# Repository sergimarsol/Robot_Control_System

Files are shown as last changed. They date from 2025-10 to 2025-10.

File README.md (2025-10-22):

# MSP430FR2355 Robot Control System

This repository contains the complete development of a robotic control system based on the MSP430FR2355 microcontroller. The project encompasses hardware design, embedded software development, real-time control implementation, and autonomous behavior strategies. All stages—from conceptual engineering to full system deployment—were carried out by a single author.

## Project Overview

The system enables robot control through multiple operational modes, leveraging a modular driver-based firmware architecture. It integrates input devices, actuators, and display components to provide both manual and autonomous control functionalities. The hardware was designed, assembled, debugged, and calibrated to ensure correct interaction among all peripherals.

### Control Modes
- **Joystick Mode**: Manual navigation using an analog joystick.
- **Light-Following Mode**: Robot movement directed toward the strongest detected light using LDR readings.
- **Line-Following Mode**: Ground sensor-based autonomous navigation via line detection.
- **Main Menu Interface**: LCD-driven user interface navigated using the joystick.

## Hardware Architecture

| Component | Description |
|---|---|
| MSP430FR2355 MCU | Core controller handling I2C, ADC, timers, GPIOs |
| 32.7KHz Crystal | Clock stabilization |
| SBW Connector | Programming and debugging interface |
| LCD 16x2 (I2C) | Displays system information and menu |
| Joystick | Directional input for manual control and navigation |
| LDR Sensors (ADC) | Detect light intensity for autonomous movement |
| Motor Driver (I2C) | Controls wheel motors for robot movement |
| RGB LEDs (I2C) | Status indication |
| ESP-01 Module (UART) | Planned Wi-Fi communication support |

## Software Architecture

The firmware was implemented with a modular structure to maximize maintainability and reusability.

| Module | Purpose |
|---|---|
| `main.c` | System initialization and main control loop |
| `timer.h` | Timer configuration, delays, millisecond counter ISR |
| `i2c.h` | I2C communication management and ISR |
| `lcd.h` | LCD initialization and text display functions |
| `leds.h` | RGB LED color control |
| `motors.h` | Motor control for direction and velocity |
| `joystick.h` | Joystick reading and movement triggering |
| `adc.h` | Light sensor acquisition and averaging |
| `sensors.h` | Line detection and autonomous path adjustment |

## Proposed Repository Structure

```
MSP430-Robot-Control-System
├── hardware/
│   ├── SergiMarsol_Gerber/                  # Gerber manufacturing outputs
│   ├── SergiMarsol_projecte_MISE.kicad_pro  # KiCad project file
│   ├── SergiMarsol_projecte_MISE.kicad_sch  # Schematic design
│   ├── SergiMarsol_projecte_MISE.kicad_pcb  # PCB layout
│   ├── SergiMarsol_projecte_MISE-backups/   # KiCad auto-backups
│   ├── SergiMarsol_projecte_MISE.kicad_prl  # KiCad project local settings
│   ├── fp-info-cache                        # Footprint cache
│   └── fp-lib-table                         # Footprint library table
├── firmware/
│   ├── ADC.c
│   ├── ADC.h
│   ├── i2c.c
│   ├── i2c.h
│   ├── joystick.c
│   ├── joystick.h
│   ├── lcd.c
│   ├── lcd.h
│   ├── leds.c
│   ├── leds.h
│   ├── motors.c
│   ├── motors.h
│   ├── sensors.c
│   ├── sensors.h
│   ├── timer.c
│   ├── timer.h
│   ├── main.c
│   ├── lnk_msp430fr2355.cmd                 # Linker command file
│   ├── Debug/                               # Compilation artifacts
│   └── targetConfigs/                       # MCU target configuration files
├── documents/
│   └── presentation.pdf                       # Final presentation of the project (in Catalan)
└── README.md
```

## Development Highlights

| Phase | Achievement |
|---|---|
| Concept Engineering | Block diagrams, requirements, planning |
| Hardware Implementation | Complete schematic design, assembly, correction of ADC pin assignments |
| Software Implementation | Driver-based structure enabling scalability |
| Debugging | Systematic validation using modular subsystem tests |
| Optional Expansion | UART-based Wi-Fi communication ready for future phases |

## Conclusion

The project demonstrates an end-to-end realization of an embedded robotic control system, showcasing microcontroller-based hardware integration, real-time firmware development, and autonomous control strategies. It serves as an excellent reference for modular embedded system design using the MSP430 ecosystem.

---

For future developments, planned features include remote control via Wi-Fi, telemetry reporting, and enhanced control algorithms such as PID for smoother autonomous navigation.

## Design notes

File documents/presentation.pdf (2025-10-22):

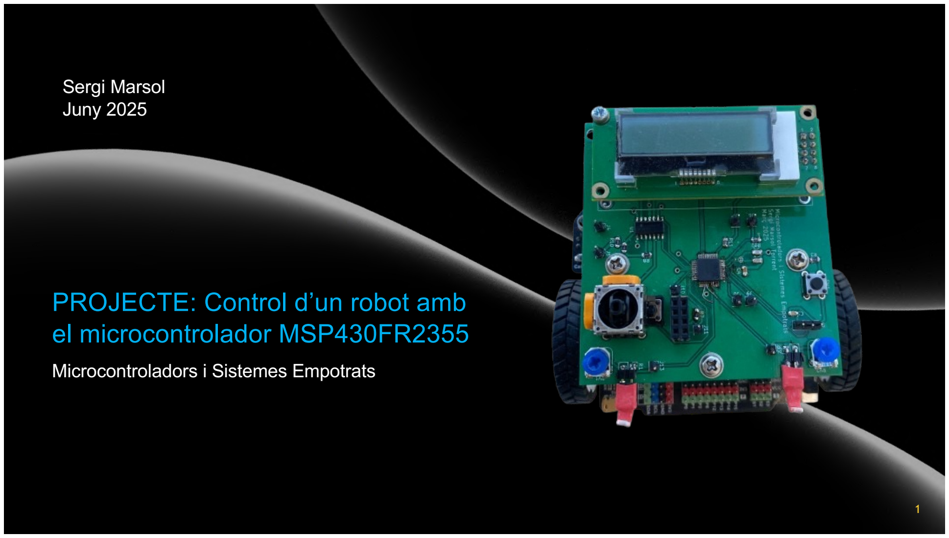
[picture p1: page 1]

## PROJECTE: Control d’un robot amb el microcontrolador MSP430FR2355

Microcontroladors i Sistemes Empotrats

Sergi Marsol
Juny 2025

1

## I N T R O D U C C I Ó

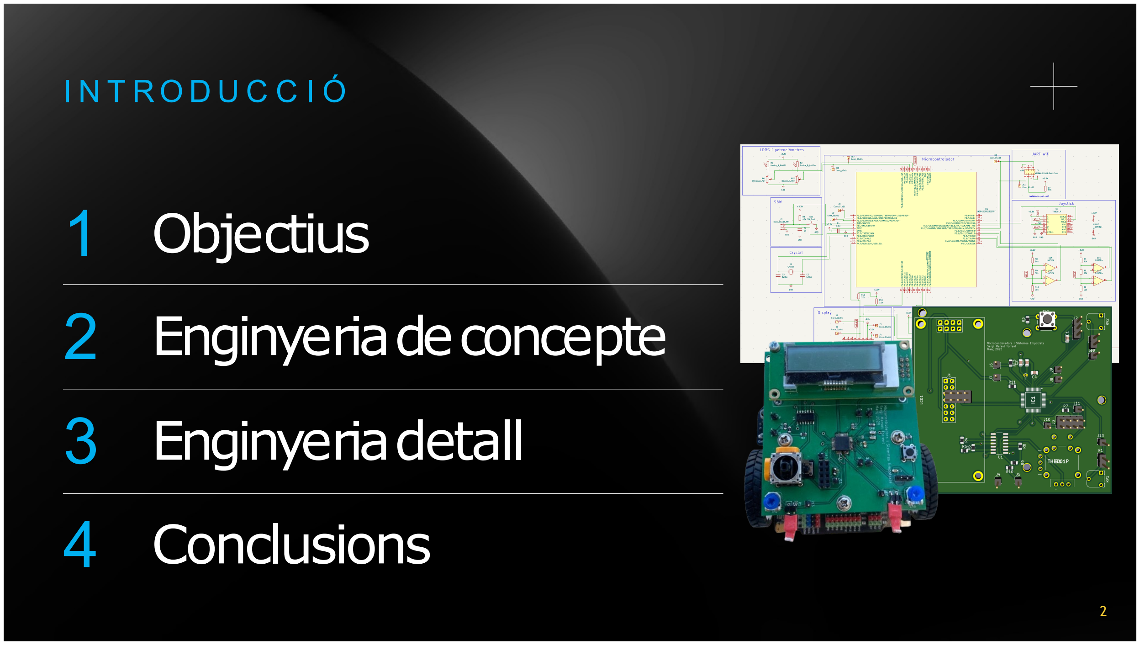
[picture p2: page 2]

1
2
3
4

# Objectius Enginyeriadeconcepte

# Enginyeriadetall

# Conclusions

2

# OBJECTIUS

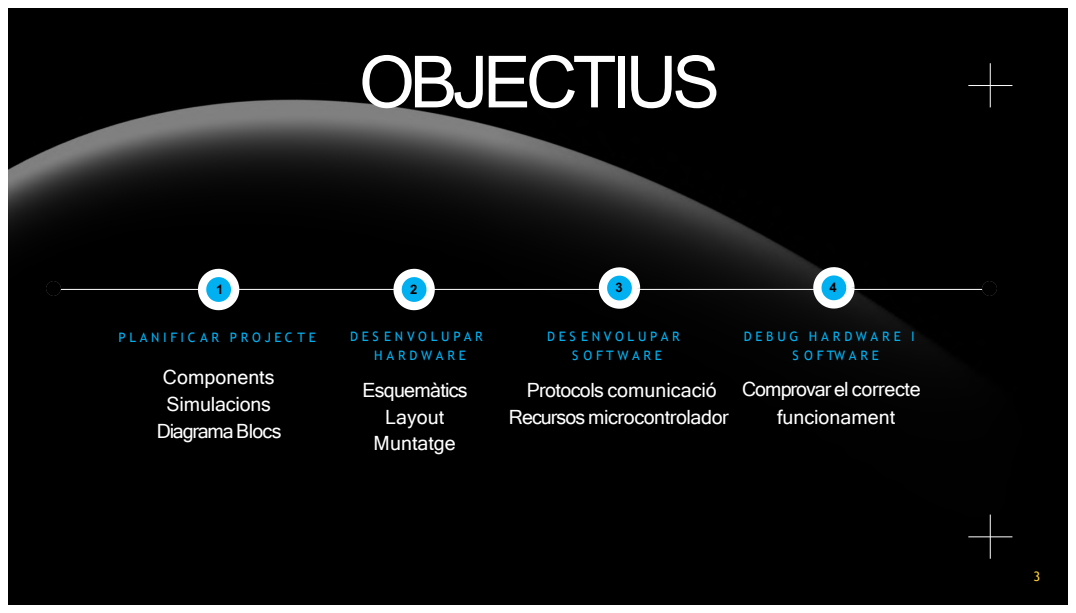
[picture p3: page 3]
Esquemàtics Layout Muntatge; Protocols comunicació Recursos microcontrolador; Components Simulacions DiagramaBlocs

Comprovar el correcte
funcionament

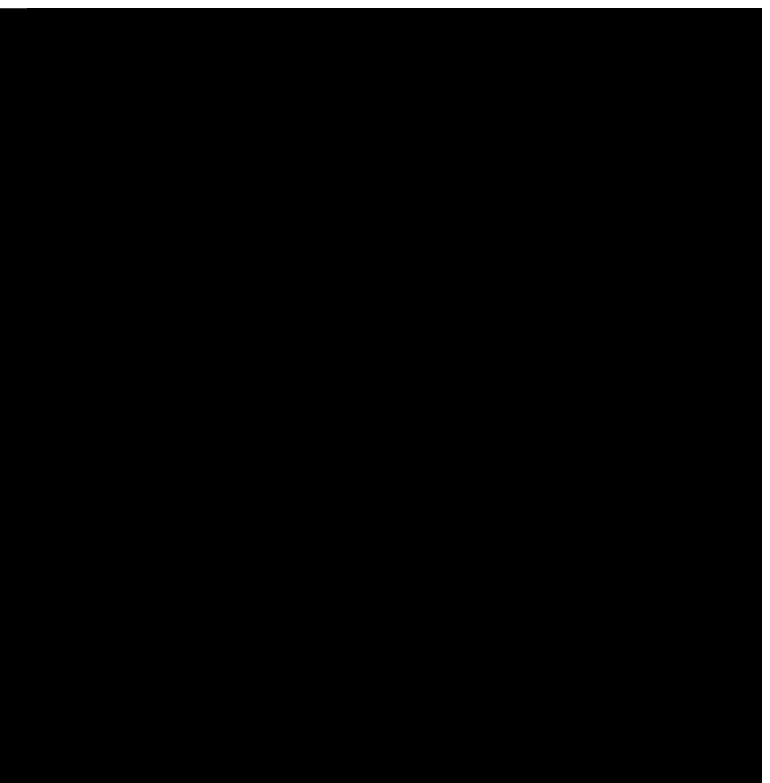
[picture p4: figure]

# ENGINYERIADECONCEPTE

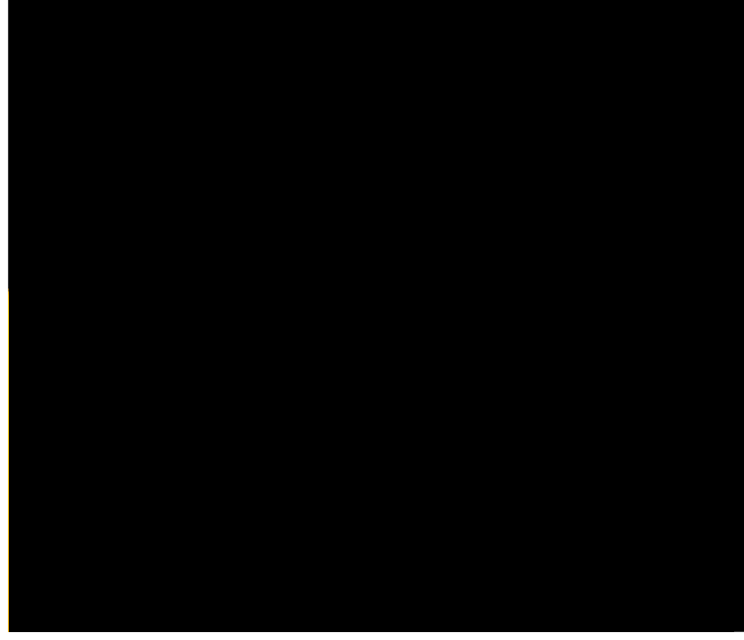
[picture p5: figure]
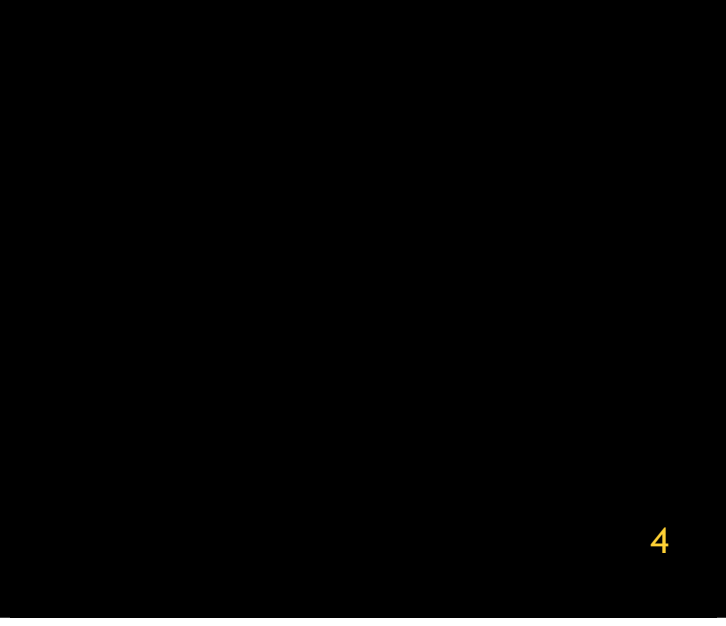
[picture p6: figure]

# REQUERIMENTS

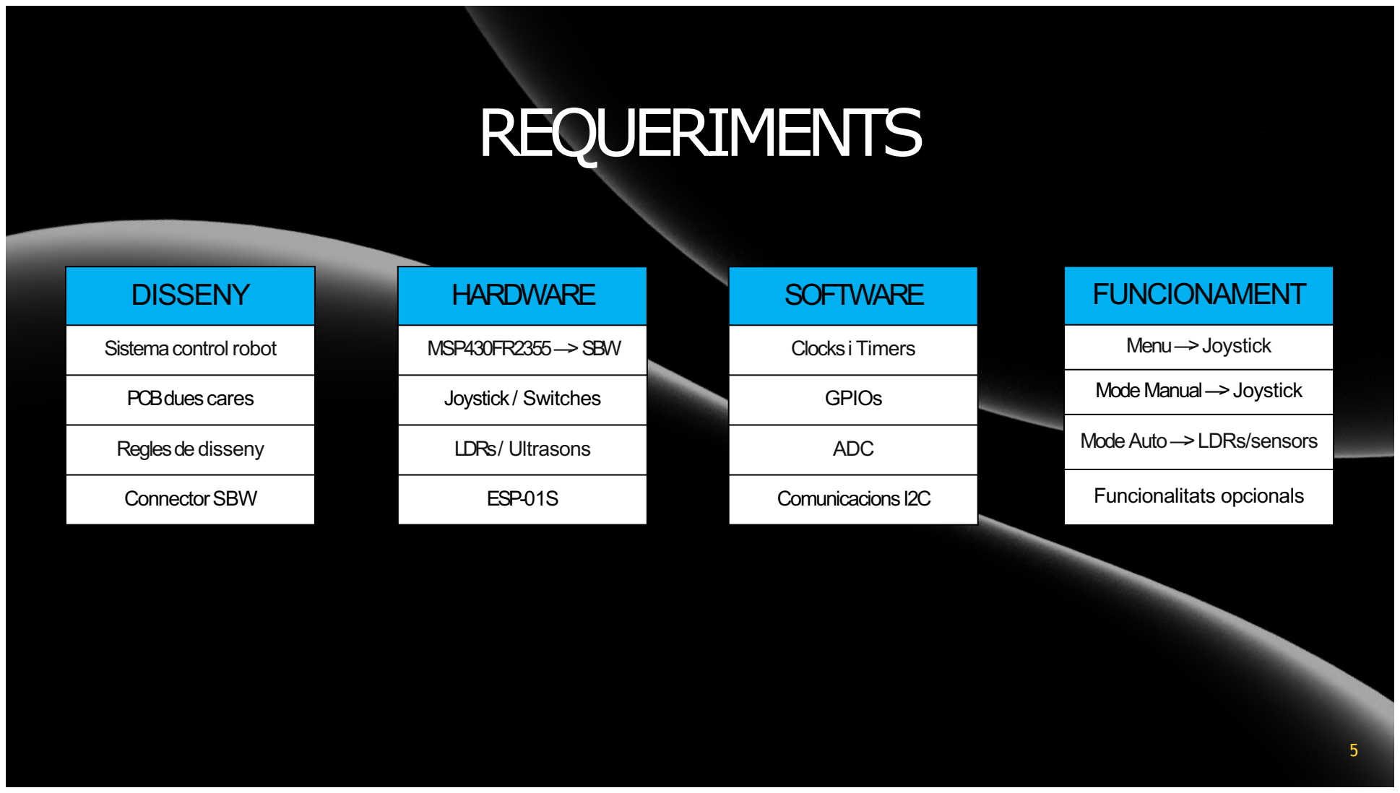
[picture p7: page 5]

### DISSENY

Sistemacontrolrobot

PCBduescares

Reglesde disseny

ConnectorSBW

### HARDWARE

MSP430FR2355—>SBW

Joystick / Switches

LDRs/ Ultrasons

ESP-01S

### SOFTWARE

Clocksi Timers

GPIOs

ADC

ComunicacionsI2C

### FUNCIONAMENT

Menu—>Joystick

Mode Manual—>Joystick

ModeAuto—>LDRs/sensors

Funcionalitats opcionals

5

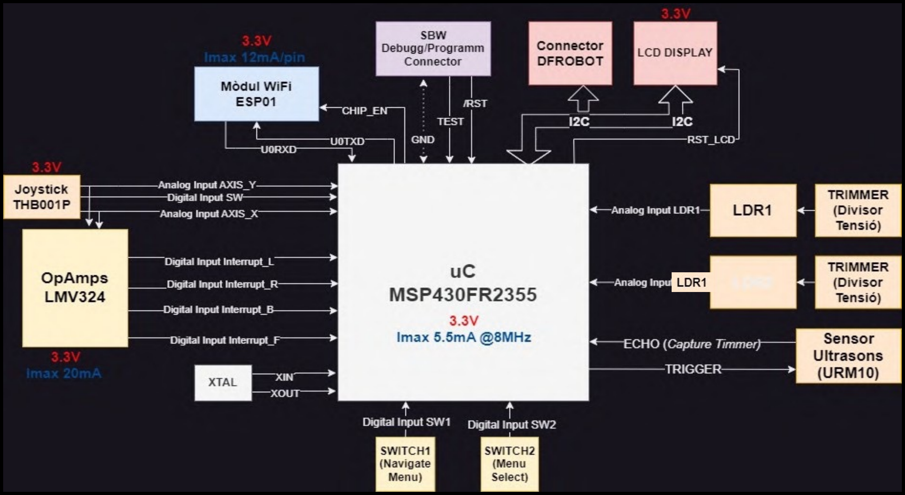
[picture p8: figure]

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
# ENGINYERIADE DETALL

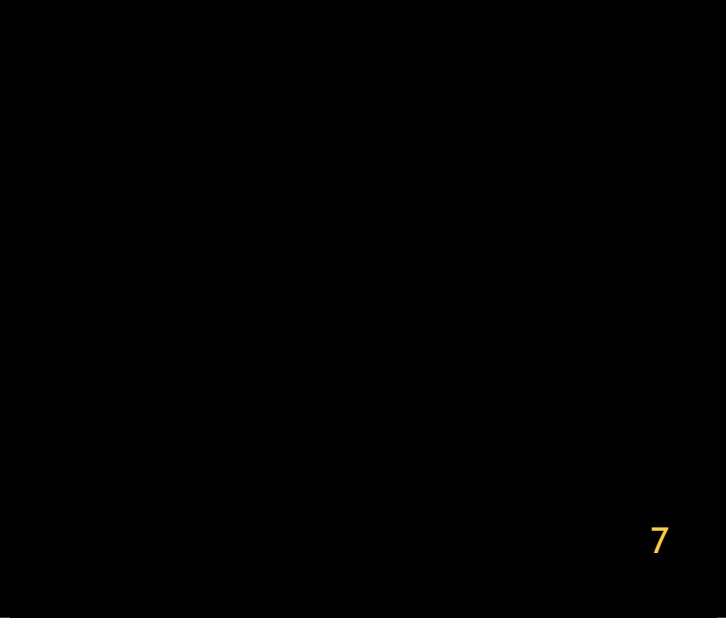
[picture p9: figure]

# HARDWARE

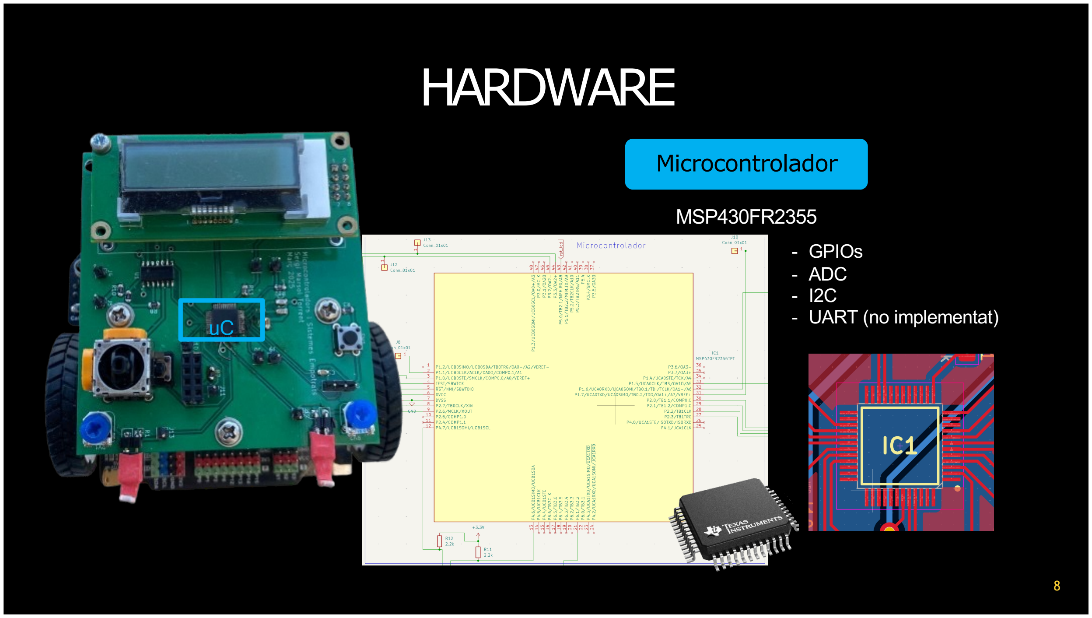
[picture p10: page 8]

uC

## Microcontrolador

MSP430FR2355
- GPIOs
- ADC
- I2C
- UART (no implementat)

8

# HARDWARE

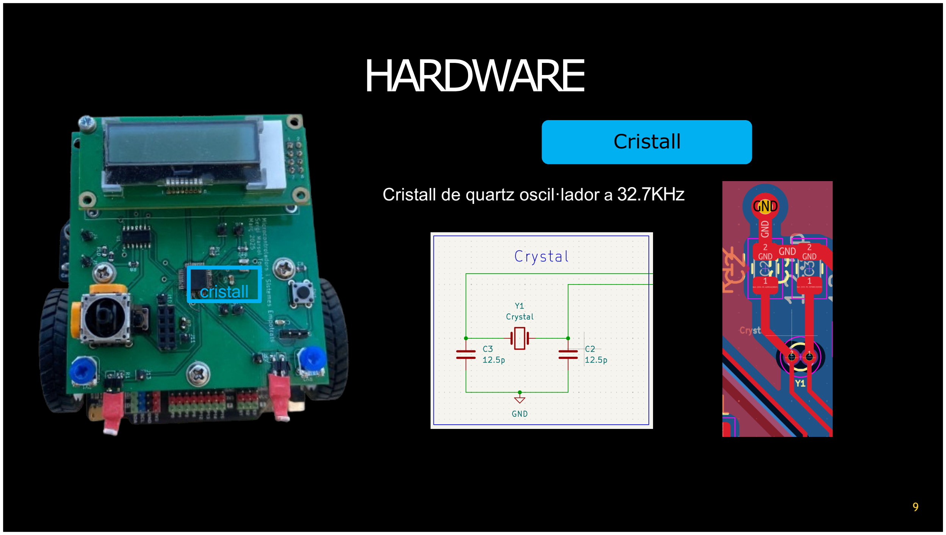
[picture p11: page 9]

## Cristall

Cristall de quartz oscil·lador a 32.7KHz

cristall

9

# HARDWARE

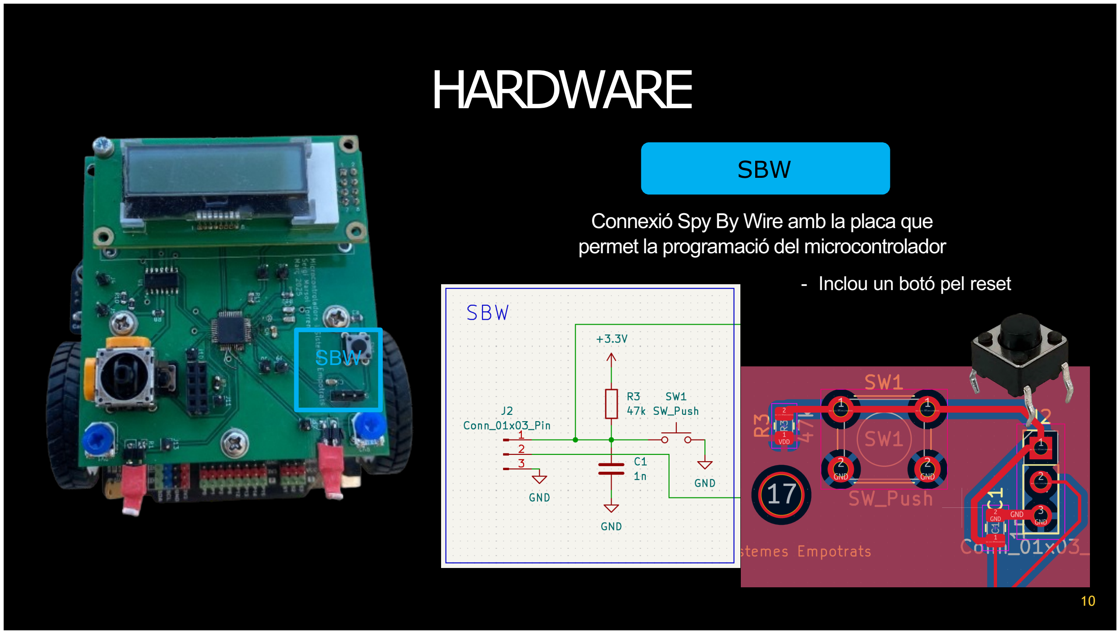
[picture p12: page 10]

## SBW

Connexió Spy By Wire amb la placa que permet la programació del microcontrolador

SBW

- Inclou un botó pel reset

10

# HARDWARE

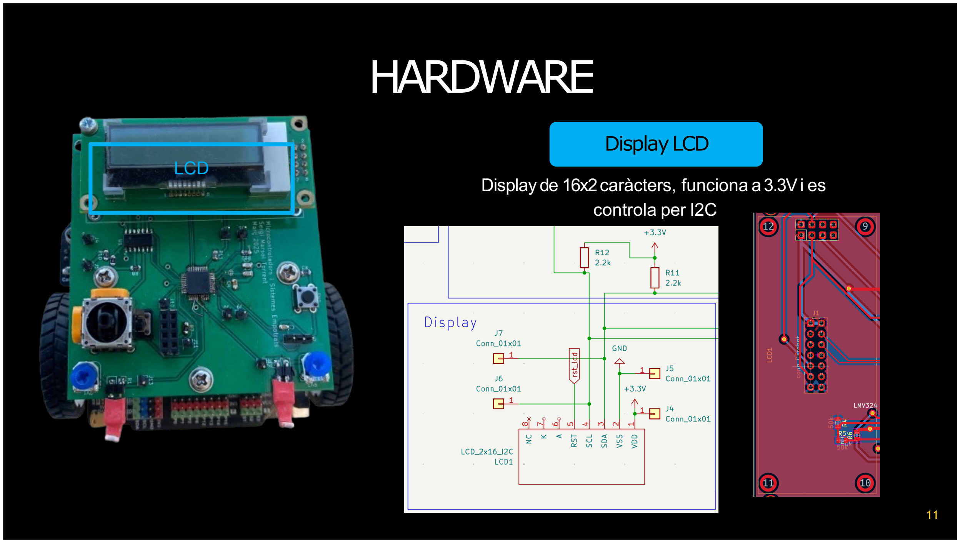
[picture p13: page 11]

## DisplayLCD

Display de 16x2caràcters, funciona a3.3Vi es controla per I2C

LCD

11

# HARDWARE

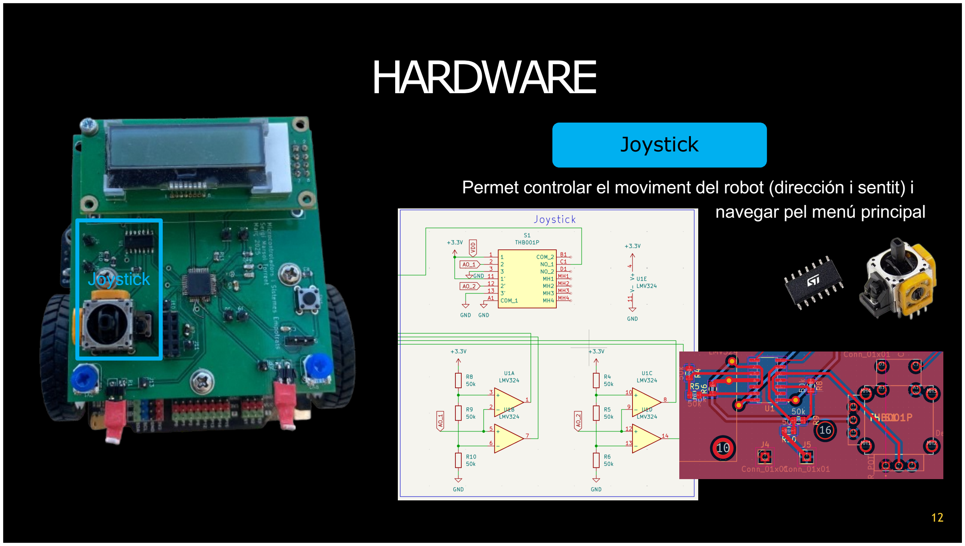
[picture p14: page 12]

## Joystick

Joystick

Permet controlar el moviment del robot (dirección i sentit) i navegar pel menú principal

12

# HARDWARE

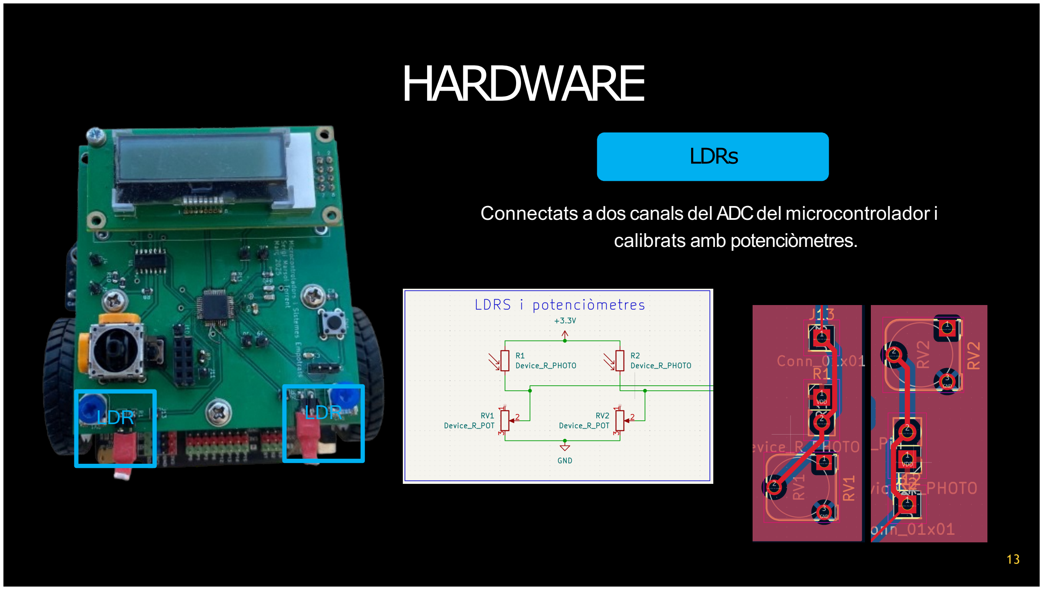
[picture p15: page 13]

## LDRs

Connectats a dos canals del ADC del microcontrolador i calibrats amb potenciòmetres.

LDR | LDR

13

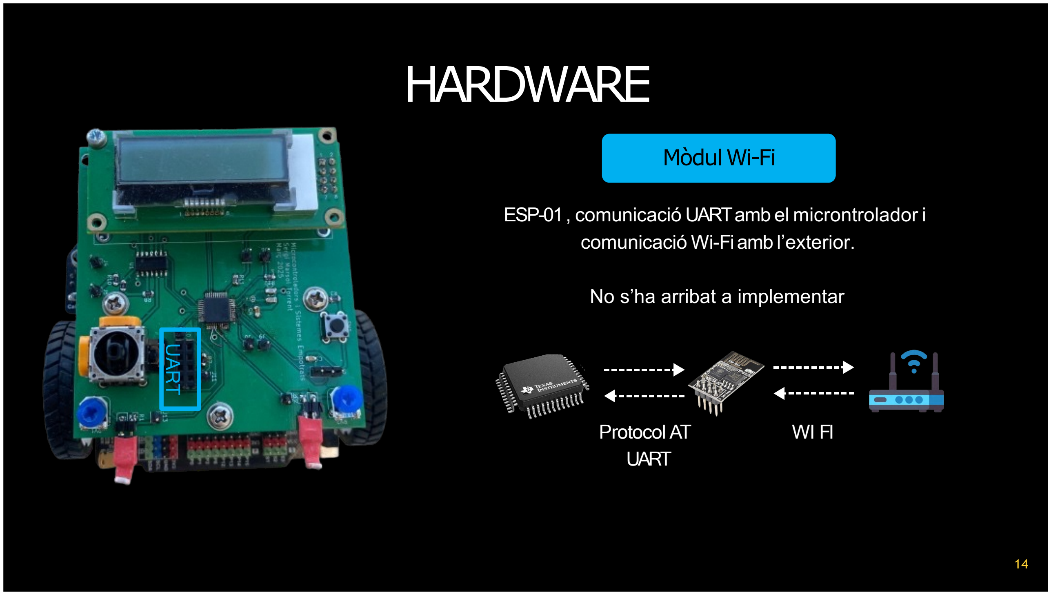
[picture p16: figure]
HARDWARE; MòdulWi-Fi; comunicació Wi-Fi amb l’exterior.; No s’ha arribat a implementar; Protocol AT UART; UART

ESP-01, comunicació UARTamb el microntrolador i

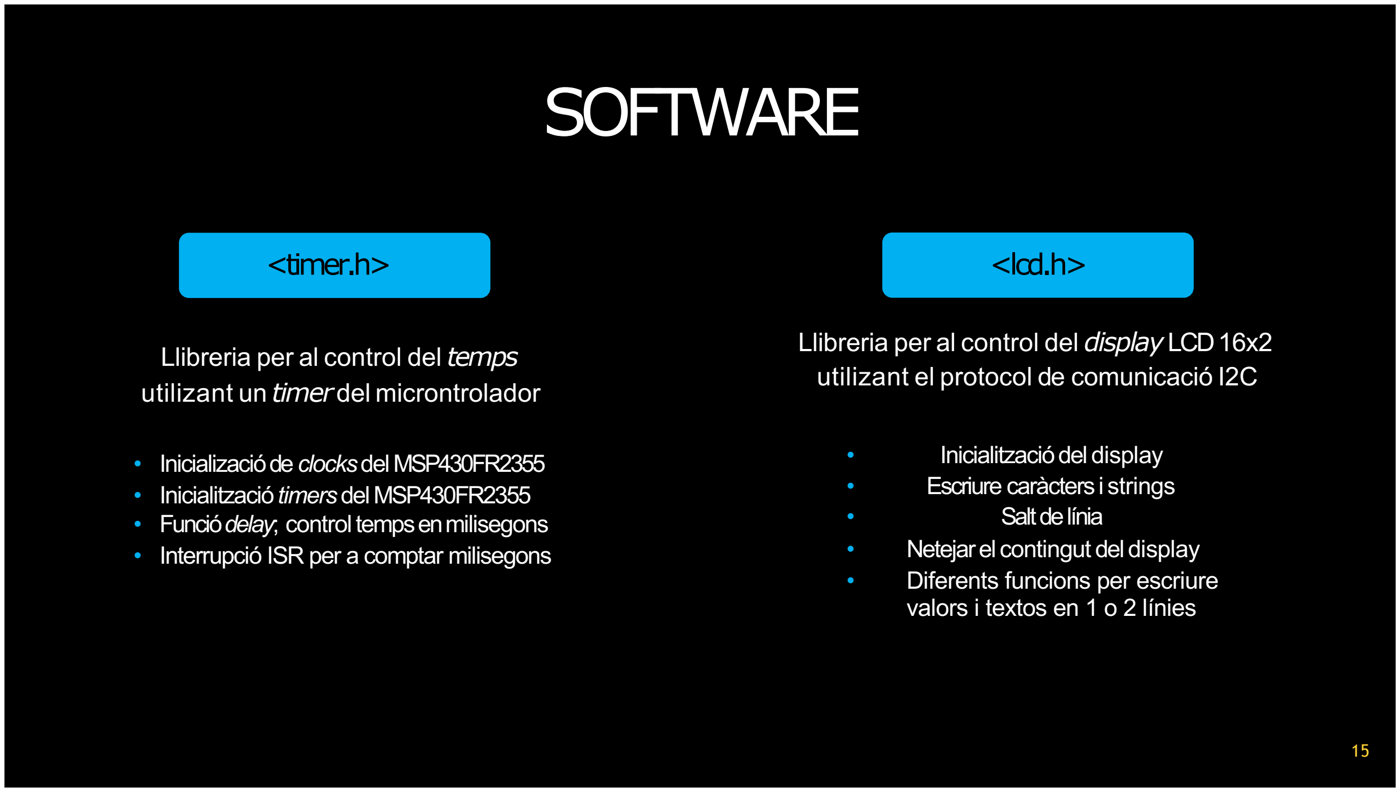
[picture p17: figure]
SOFTWARE; <timer.h>; Llibreria per al control del temps utilizant un timerdel microntrolador; • Inicializacióde clocksdel MSP430FR2355 • Inicialitzaciótimers del MSP430FR2355 • Funciódelay; control tempsenmilisegons; <lcd.h>; • Inicialitzaciódel display • Escriure caràcters i strings • Salt de línia • Netejarel contingut deldisplay • Diferents funcions per escriure valors i textos en 1 o 2 línies

- Interrupció ISR per a comptar milisegons

Llibreria per al control del displayLCD16x2 utilizant el protocol de comunicació I2C

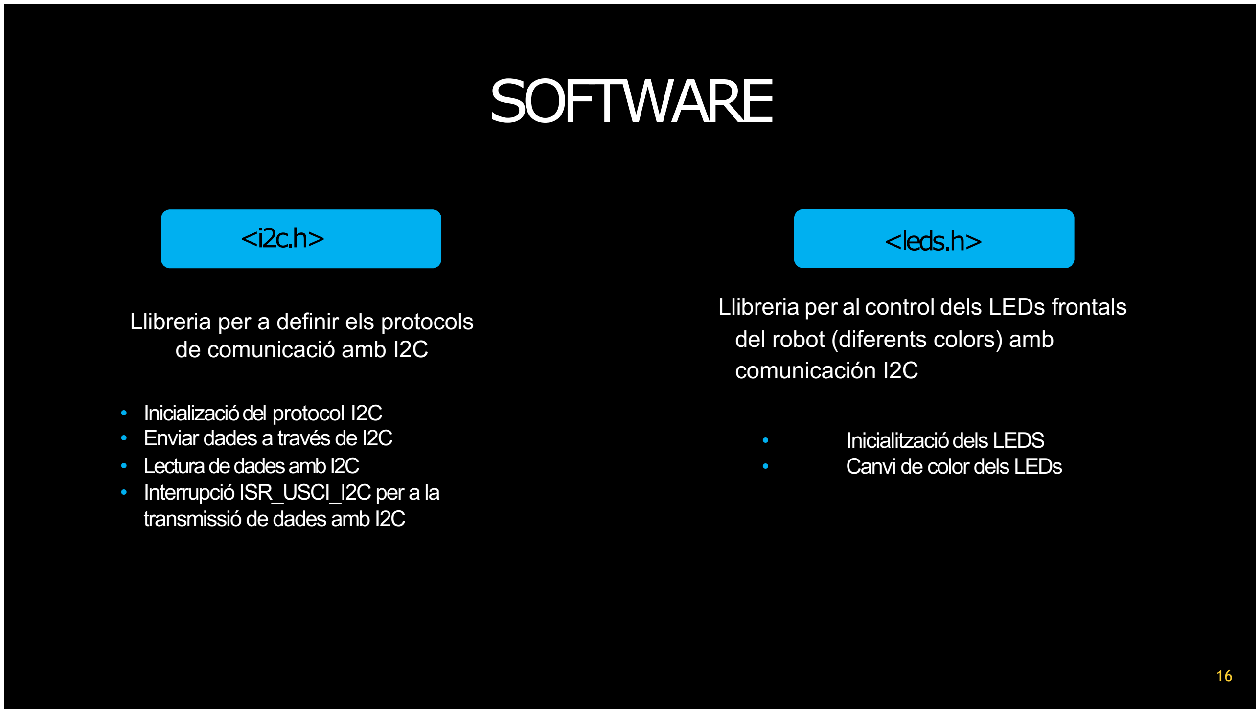
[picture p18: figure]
SOFTWARE; Llibreria per a definir els protocols de comunicació amb I2C; • Inicializaciódel protocol I2C • Enviar dades a través de I2C • Lectura de dades ambI2C • Interrupció ISR_USCI_I2C per a la transmissió de dades amb I2C; <leds.h>; del robot (diferents colors) amb comunicación I2C; • Inicialitzaciódels LEDS • Canvi de color dels LEDs

Llibreria per al control dels LEDs frontals

# SOFTWARE

## <motors.h>

Llibreria per a definir el moviment dels motors de les rodes amb comunicació I2C

- Inicializaciódels motors
- Moviment dels motors donades direccions i velocitat
- Movimentsdel robot en totes direccions (endavant, enrere, dreta, esquerra, aturat)

17

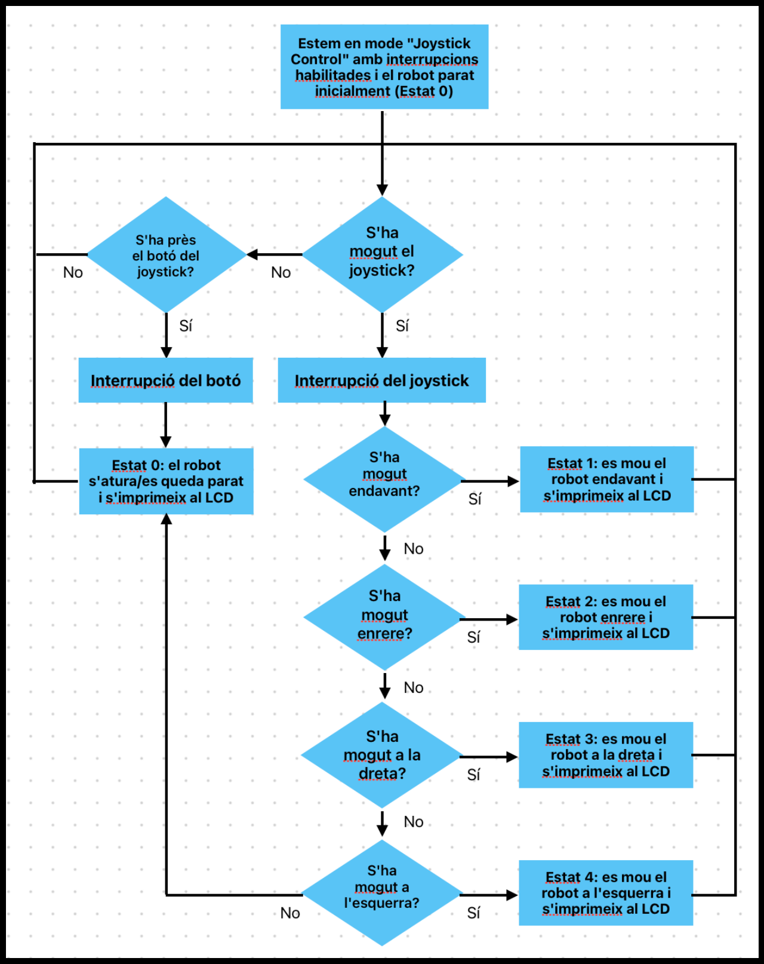
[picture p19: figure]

# SOFTWARE

## <joystick.h>

Llibreria per a la lectura del joystick i el moviment del robot usant-lo

- Inicializaciódel joystick
- Iniciaitzaciódel botódel joystick
- Funcióperdetectarladirecciódel joystick i enviarlacomandaperI2Calmotor
- ISRperladetecciódelssenyalsdel joystick
- ISR per al botó del joystick

F I G U R A 2: DIAGRAMA DE FLUX DEL CONTROL PER JOYSTICK

18

Llibreria per a la lectura dels LDRS i el moviment del robot en la direcció de la llum
- InicializaciódelADC
- Inicialitzar una mesura per el LDR indicat
- Controlar el movement del robot per seguir la llum
- ISR per prendre la mitja de 16 mesures

# SOFTWARE

## <ADC.h>

F I G U R A 3: DIAGRAMA DE FLUX DEL CONTROL PER LLUM (LDRs)

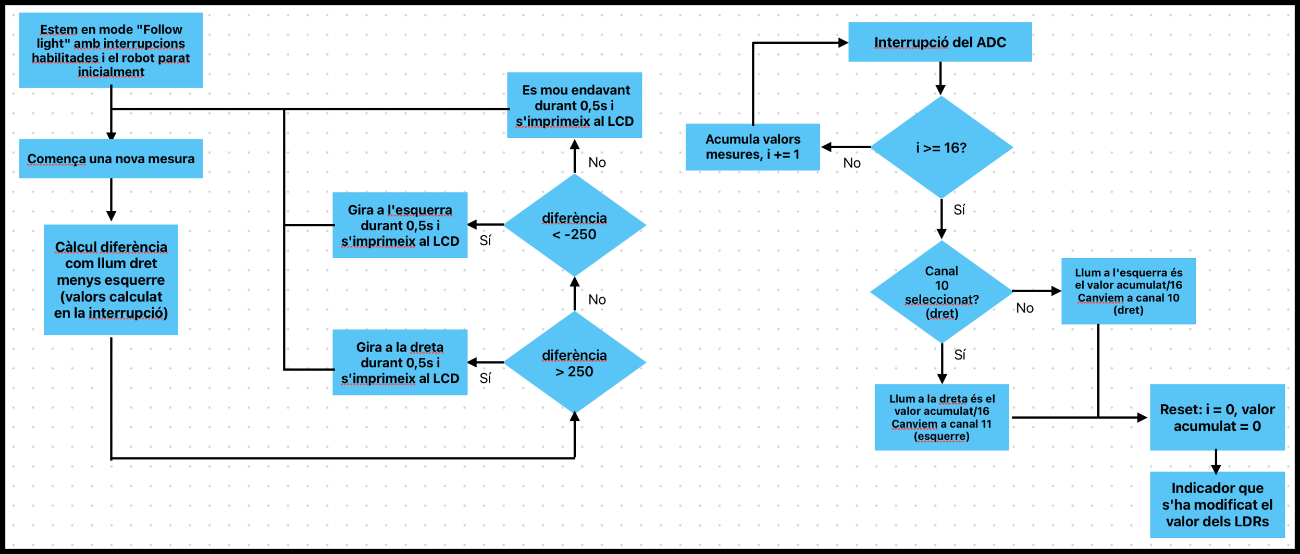
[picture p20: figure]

19

Llibreria per a la lectura dels sensors de la base del robot i el control del seu movement per a seguir línies

- Lectura dels sensors per I2C
- Moviment del robot seguint les línies del terra que es detecten amb els sensors

# SOFTWARE

## <sensors.h>

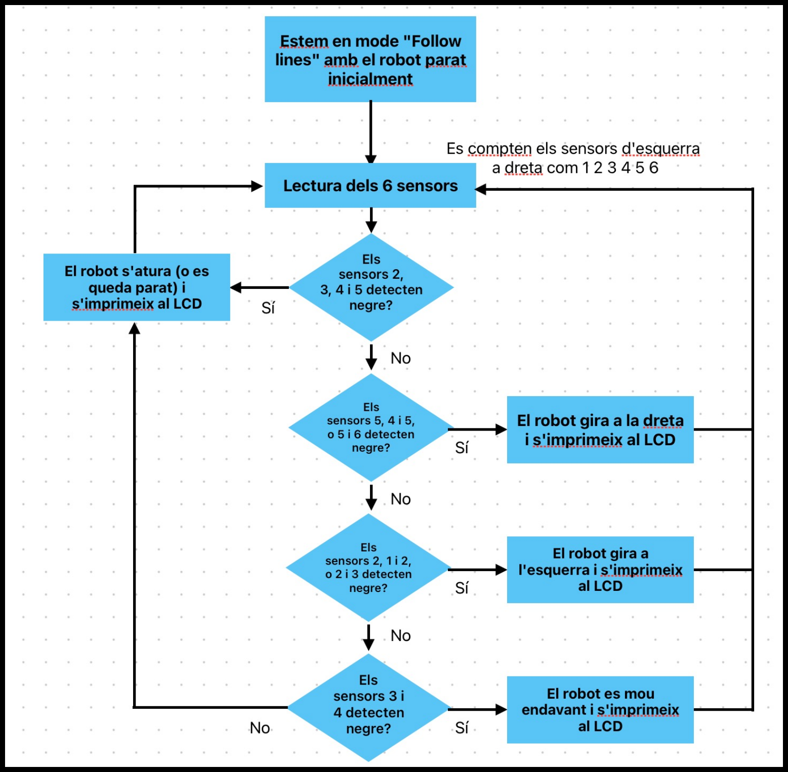
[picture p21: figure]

F I G U R A 4: DIAGRAMA DE FLUX DEL CONTROLPER SEGUIMENT DE LÍNIES | 20

# SOFTWARE <main.c>

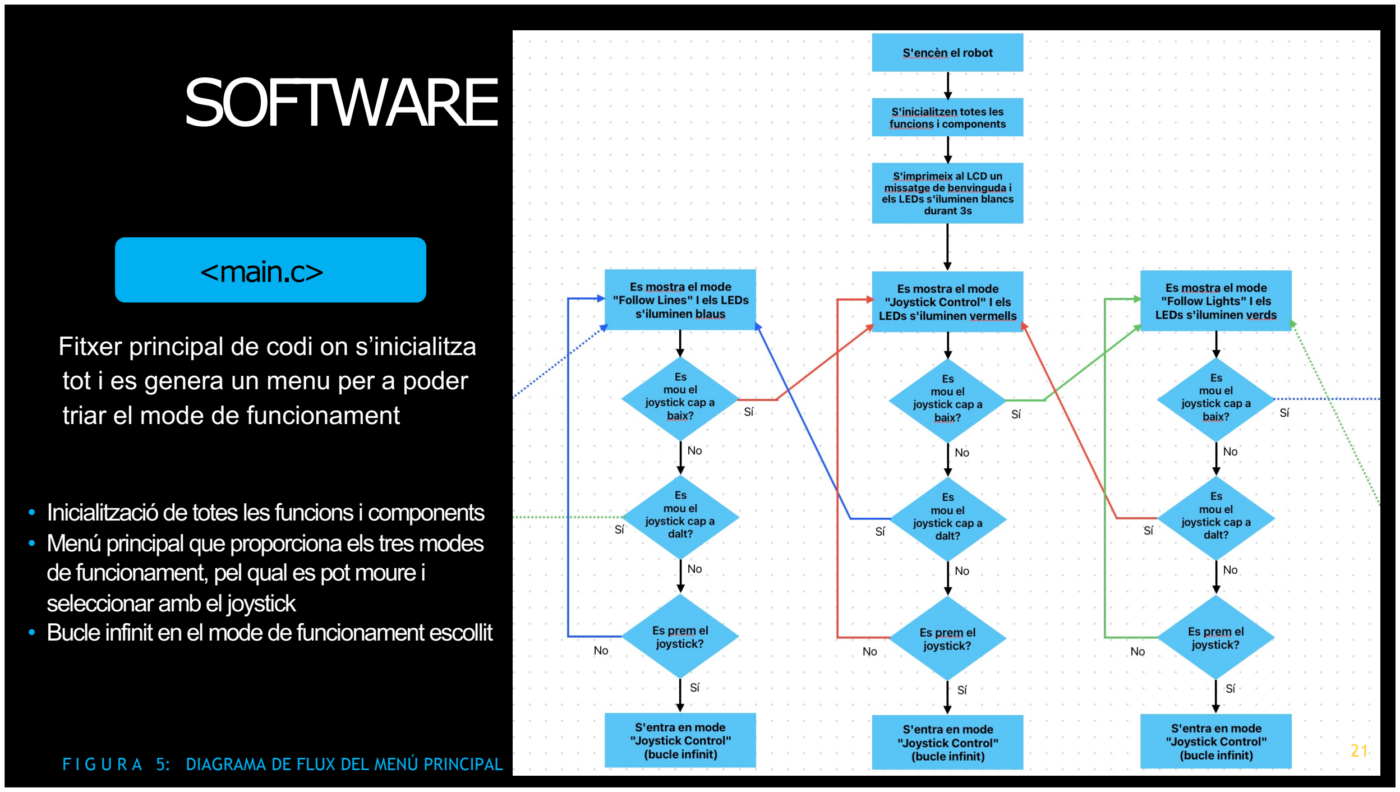
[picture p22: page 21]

Fitxer principal de codi on s’inicialitza tot

i es genera un menu per a poder triar el mode de funcionament

- Inicialització de totes les funcions

i components
- Menú principal que proporciona els tres modes de funcionament, pel qual es pot moure

i
seleccionar amb el joystick
- Bucle infinit en el mode de funcionament escollit

F

I

G

U

R

A

5

: DIAGRAMA DE FLUX DEL MENÚ PRINCIPAL | 21

### S’ha dut a terme una bona planificació del projecte amb components

adequats i un diagrama de blocs complets.

La implementación a nivel hardware s’ha aconseguit de forma satisfactòria,

### però ha calgut canviar el microcontrolador i dues pistes perquè s’havien

conectat a pins senseADC.

Unbon disseny del hardware facilita el debug i la programació del sistema.

### El software s’ha implementat exitosament de manera que ha permés proporcionar totes les funcionalitats obligatòries i algunes de les

opcionals (seguiment de línies).

### En general s’ha aconseguit un projecte complet i functional tot i els

imprevistos que han sorgit i el fet d’haver realitzat el projecte sol.

# CONCLUSIONS

22

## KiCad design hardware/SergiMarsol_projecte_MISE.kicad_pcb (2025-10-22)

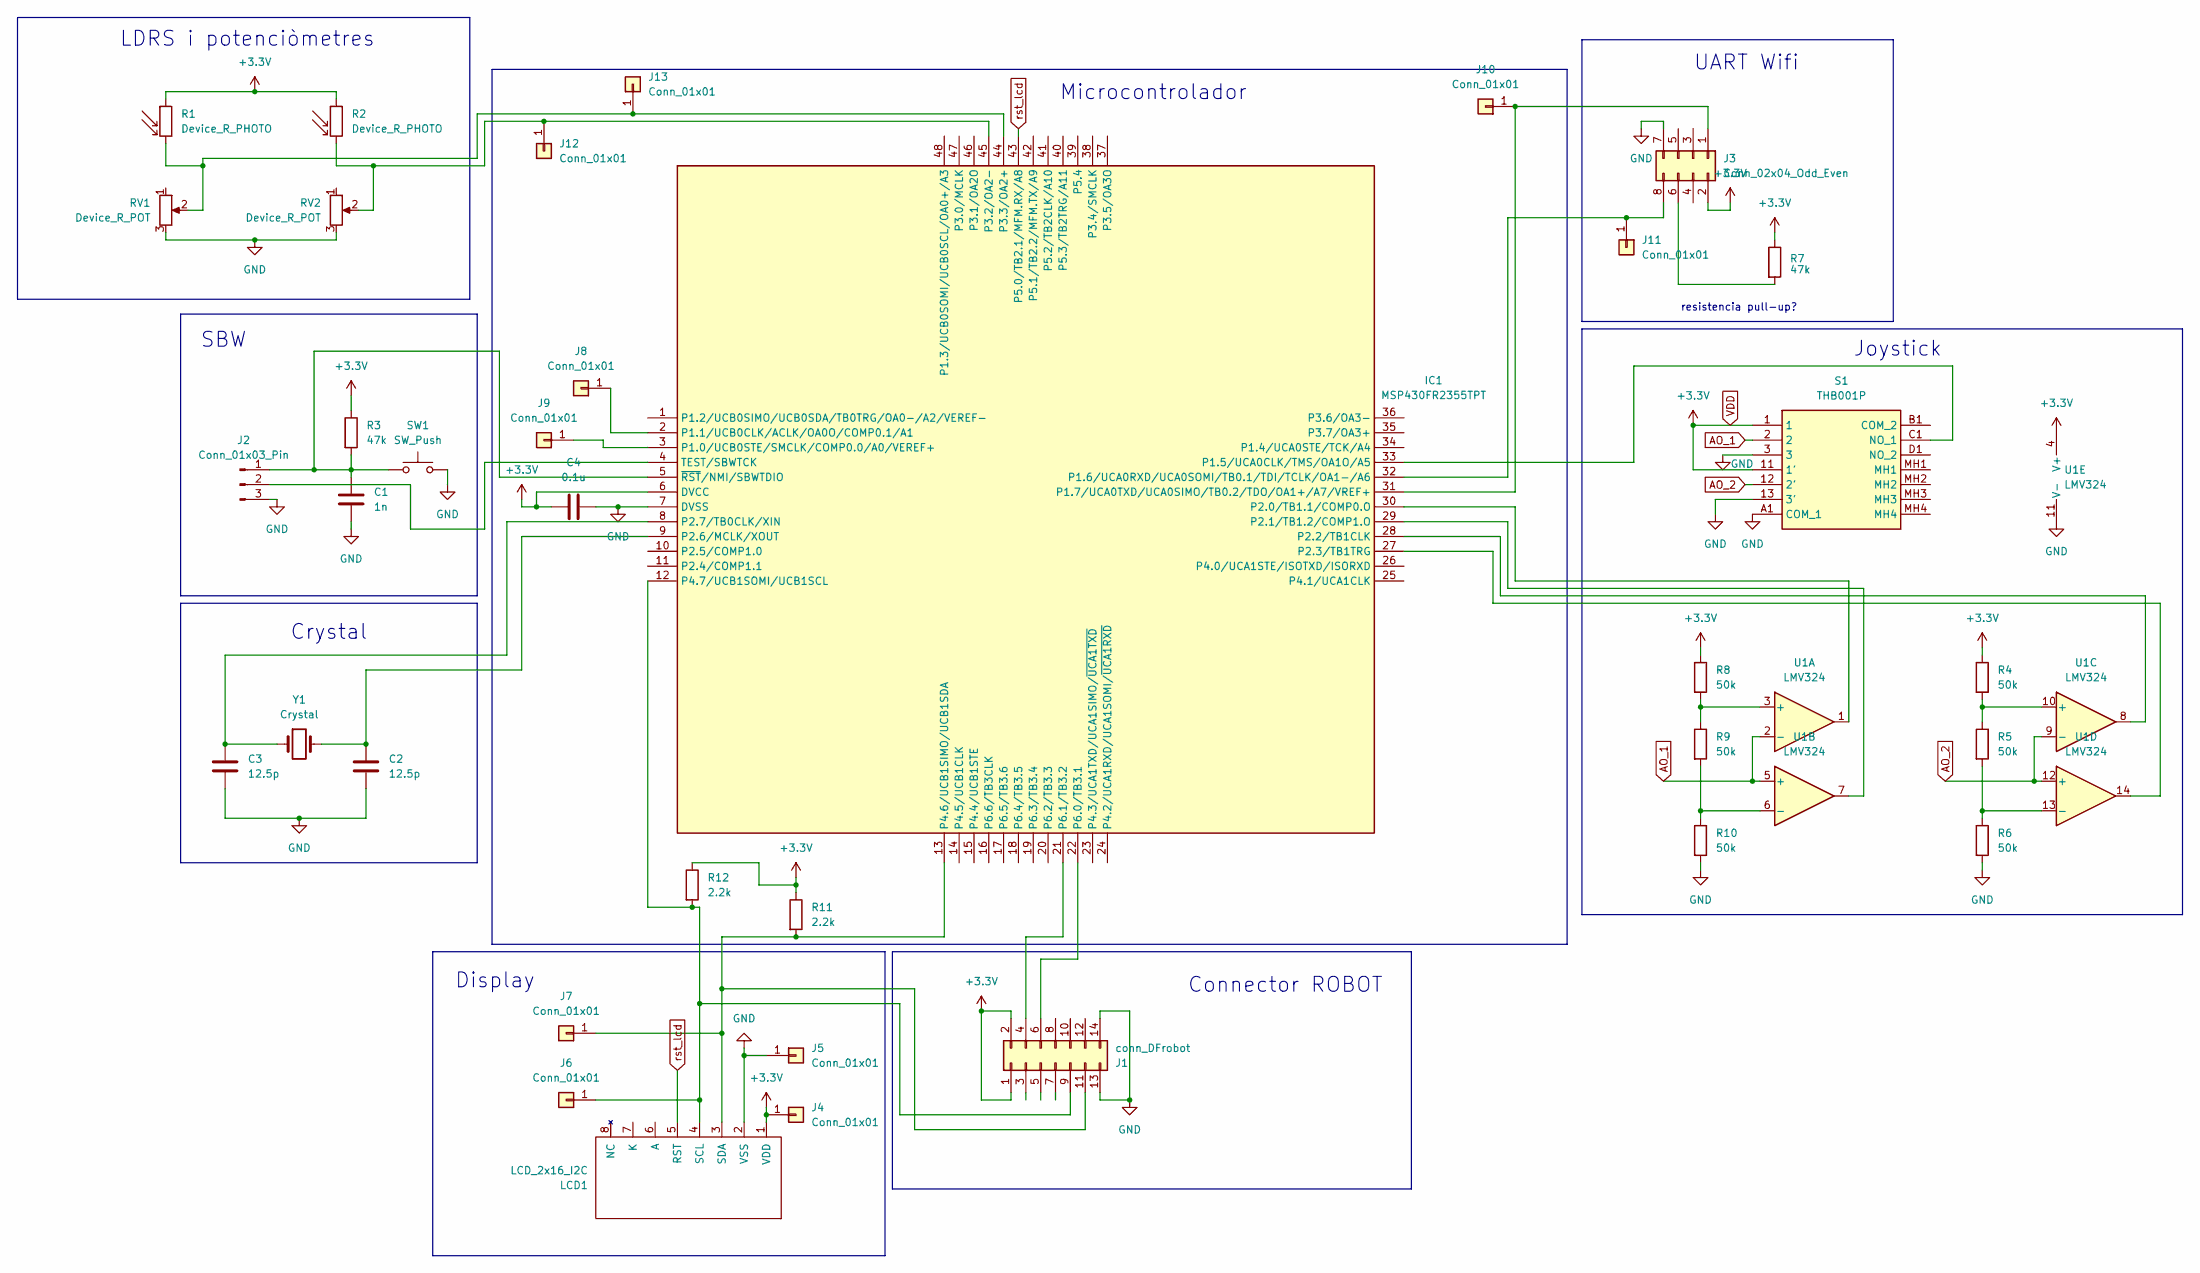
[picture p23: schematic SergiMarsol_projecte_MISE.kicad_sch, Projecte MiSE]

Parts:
C1: 1n; C_0805_2012Metric
C2, C3: 12.5p; C_0805_2012Metric
C4: 0.1u; C_0805_2012Metric
IC1: MSP430FR2355TPT; QFP50P900X900X160-48N; Manufacturer_Part_Number MSP430FR2355TPT; Mouser Part Number 595-MSP430FR2355TPT
J1: conn_DFrobot
J2: Conn_01x03_Pin; PinHeader_1x03_P2.54mm_Vertical
J3: Conn_02x04_Odd_Even; PinHeader_2x04_P2.54mm_Vertical
J4, J5, J6, J7, J8, J9, J10, J11, J12, J13: Conn_01x01; PinHeader_1x01_P2.54mm_Vertical
LCD1: LCD_2x16_I2C; LCD_2x16_I2C(Midas)
R1, R2: Device_R_PHOTO; LDR
R3, R7: 47k; R_0805_2012Metric
R4, R5, R6, R8, R9, R10: 50k; R_0805_2012Metric
R11, R12: 2.2k; R_0805_2012Metric
RV1, RV2: Device_R_POT; Trimmer_MiSE
S1: THB001P; Manufacturer_Part_Number THB001P; Mouser Part Number 611-THB001P
SW1: SW_Push; SW_PUSH_6mm_H4.3mm
U1: LMV324; SOIC127P600X175-14N
Y1: Crystal; XTAL_ECS-.327-8-14

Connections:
AO_1: S1.2, U1.2 (-), U1.5 (+)
AO_2: S1.12 (2'), U1.9 (-), U1.12 (+)
GND: C1.2, C2.2, C3.2, C4.2, IC1.7 (DVSS), J1.13, J1.14, J2.3, J3.7, J5.1, LCD1.2 (VSS), R6.2, R10.2, RV1.3, RV2.3, S1.3, S1.13 (3'), S1.A1 (COM_1), SW1.2, U1.11 (V-)
unnamed: IC1.3 (P1.0/UCB0STE/SMCLK/COMP0.0/A0/VEREF+), J9.1
unnamed: IC1.2 (P1.1/UCB0CLK/ACLK/OA0O/COMP0.1/A1), J8.1
unnamed: IC1.33 (P1.5/UCA0CLK/TMS/OA1O/A5), S1.C1 (NO_1)
unnamed: IC1.32 (P1.6/UCA0RXD/UCA0SOMI/TB0.1/TDI/TCLK/OA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), J3.8, J11.1
unnamed: IC1.31 (P1.7/UCA0TXD/UCA0SIMO/TB0.2/TDO/OA1+/A7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), J3.1, J10.1
unnamed: IC1.30 (P2.0/TB1.1/COMP0.O), U1.1
unnamed: IC1.29 (P2.1/TB1.2/COMP1.O), U1.7
unnamed: IC1.28 (P2.2/TB1CLK), U1.8
unnamed: IC1.27 (P2.3/TB1TRG), U1.14
unnamed: C2.1, IC1.9 (P2.6/MCLK/XOUT), Y1.2
unnamed: C3.1, IC1.8 (P2.7/TB0CLK/XIN), Y1.1
unnamed: IC1.45 (P3.2/OA2-), J12.1, R2.2, RV2.2
unnamed: IC1.44 (P3.3/OA2+), J13.1, R1.2, RV1.2
unnamed: IC1.13 (P4.6/UCB1SIMO/UCB1SDA), J1.11, J7.1, LCD1.3 (SDA), R11.2
unnamed: IC1.12 (P4.7/UCB1SOMI/UCB1SCL), J1.9, J6.1, LCD1.4 (SCL), R12.2
unnamed: IC1.22 (P6.0/TB3.1), J1.6
unnamed: IC1.21 (P6.1/TB3.2), J1.4
unnamed: IC1.4 (TEST/SBWTCK), J2.2
unnamed: C1.1, IC1.5 (~RST/NMI/SBWTDIO), J2.1, R3.2, SW1.1
unnamed: J3.6, R7.2
unnamed: R8.2, R9.1, U1.3 (+)
unnamed: R9.2, R10.1, U1.6 (-)
unnamed: R4.2, R5.1, U1.10 (+)
unnamed: R5.2, R6.1, U1.13 (-)
VDD: C4.1, IC1.6 (DVCC), J1.1, J1.2, J3.2, J4.1, LCD1.1 (VDD), R1.1, R2.1, R3.1, R4.1, R7.1, R8.1, R11.1, R12.1, S1.1, S1.11 (1'), U1.4 (V+)
rst_lcd: IC1.43 (P5.0/TB2.1/MFM.RX/A8), LCD1.5 (RST)

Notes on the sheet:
UART Wifi
Crystal
Display
SBW
LDRS i potenciòmetres
resistencia pull-up?
Connector ROBOT
Microcontrolador
Joystick

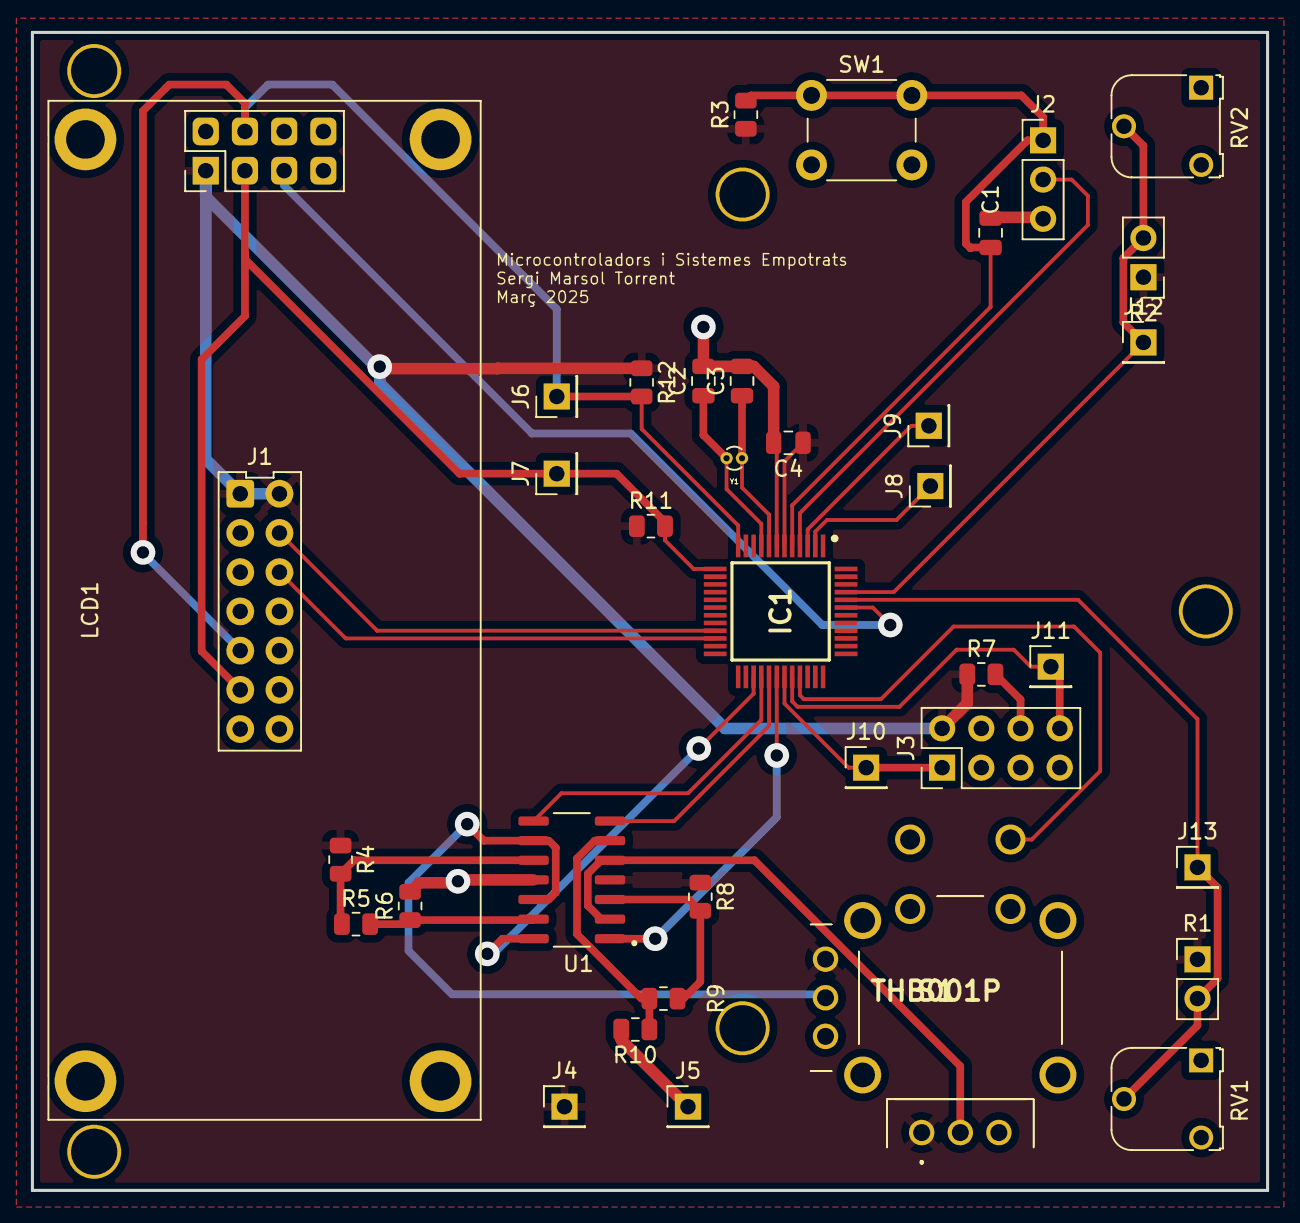
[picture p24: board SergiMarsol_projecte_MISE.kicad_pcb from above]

Board: 2 copper layers, 80.0 x 75.0 mm, 37 parts (0 on the bottom side), 29 nets.

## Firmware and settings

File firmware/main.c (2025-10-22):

// * Sergi Marsol Torrent *
// * 2023-10-30 *
// * Microcontroladors i Sistemes Empotrats *
// * Universitat de Barcelona *

#include <msp430.h> 
#include <stdint.h>
#include <stdio.h>

#include "ADC.h"
#include "timer.h"
#include "i2c.h"
#include "leds.h"
#include "lcd.h"
#include "motors.h"
#include "sensors.h"
#include "joystick.h"

/**
 * main.c
 * This file contains the main function for the robot control system.
 * It initializes the necessary components, displays the main menu on the LCD,
 * and allows the user to select a mode of operation using the joystick.
 */
main(void)
{
    WDTCTL = WDTPW | WDTHOLD;   // stop watchdog timer

    // initializations
    init_clocks();
    init_timers();
    i2c_init();
    init_leds();
    init_motors();
    init_joystick();
    init_stop_button();
    init_ADC();
    start_measure(10);
    start_measure(11);

    __enable_interrupt();

    init_LCD(); // Initialize the LCD

    write_LCD_two_lines("@Main Menu", "@Sergi Marsol"); // Display the main menu on the LCD
    delay_ms(3000); // Wait for 1 second to display the goodbye message
   
    uint8_t mode = 0; // Current mode (0 = joystick, 1 = follow lines, 2 = follow light)
    uint8_t selected_mode = 0; // Selected mode

    // Mode selection loop
    while (1) {
        if (state_joystick == 2) { // Joystick moved down
            mode = (mode + 1) % 3; // Cycle through modes (0 -> 1 -> 2 -> 0)
            switch (mode) {
                case 0:
                    write_LCD_one_line("@Joystick Control");
                    leds(RED, RED); // Set both LEDs to RED for joystick control mode
                    break;
                case 1:
                    write_LCD_one_line("@Follow Lines");
                    leds(GREEN, GREEN); // Set both LEDs to GREEN for follow lines mode
                    break;
                case 2:
                    write_LCD_one_line("@Follow Light");
                    leds(BLUE, BLUE); // Set both LEDs to BLUE for follow light mode
                    break;
            }
            delay_ms(500); // Debounce delay
            state_joystick = 255; // Reset joystick state to neutral
        } else if (state_joystick == 1) { // Joystick moved up
            mode = (mode + 2) % 3; // Cycle backward through modes (0 -> 2 -> 1 -> 0)
            switch (mode) {
                case 0:
                    write_LCD_one_line("@Joystick Control");
                    leds(RED, RED); // Set both LEDs to RED for joystick control mode
                    break;
                case 1:
                    write_LCD_one_line("@Follow Lines");
                    leds(GREEN, GREEN); // Set both LEDs to GREEN for follow lines mode
                    break;
                case 2:
                    write_LCD_one_line("@Follow Light");
                    leds(BLUE, BLUE); // Set both LEDs to BLUE for follow light mode
                    break;
            }
            delay_ms(500); // Debounce delay
            state_joystick = 255; // Reset joystick state to neutral
        } else if (state_joystick == 0) { // Joystick button pressed
            selected_mode = mode; // Select the current mode
            break; // Exit the mode selection loop
        }
    }

    // Infinite loop for the selected mode
    while (1) {
        switch (selected_mode) {
            case 0: // Joystick control mode
                control_movement_joystick(state_joystick, 50);
                break;
            case 1: // Follow lines mode
                control_movement_lines(50);
                break;
            case 2: // Follow light mode
                control_movement_light(50);
                break;
        }
        delay_ms(100); // Small delay to prevent excessive CPU usage
    }
}

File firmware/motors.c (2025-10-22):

// * Sergi Marsol Torrent *
// * 2023-10-30 *
// * Microcontroladors i Sistemes Empotrats *
// * Universitat de Barcelona *

#include "motors.h"
#include "i2c.h"

#define ADDR 0x10 // I2C address for motors

void init_motors(void){
    uint8_t i2c_buffer_motors[5];
    i2c_buffer_motors[0]=0x00; //device: motors
    i2c_buffer_motors[1]=1;
    i2c_buffer_motors[2]=0;
    i2c_buffer_motors[3]=1;
    i2c_buffer_motors[4]=0;
    I2C_send(ADDR, i2c_buffer_motors, 5); // Enviar dades
}

void motors(uint8_t motor1_dir, uint8_t motor1_speed, uint8_t motor2_dir, uint8_t motor2_speed) {
    uint8_t i2c_buffer_motors[5];
    i2c_buffer_motors[0] = 0x00; // Device: motors
    i2c_buffer_motors[1] = motor1_dir;    // Motor 1 direction
    i2c_buffer_motors[2] = motor1_speed;  // Motor 1 speed
    i2c_buffer_motors[3] = motor2_dir;    // Motor 2 direction
    i2c_buffer_motors[4] = motor2_speed;  // Motor 2 speed
    I2C_send(ADDR, i2c_buffer_motors, 5); // Send data to motors
}

void forward(uint8_t speed) {
    motors(1, speed, 1, speed); // Move both motors forward
}

void backward(uint8_t speed) {
    motors(2, speed, 2, speed); // Move both motors backward
}

void turn_left(uint8_t speed) {
    motors(0, speed, 1, speed); // Turn left
}  

void turn_right(uint8_t speed) {
    motors(1, speed, 0, speed); // Turn right
}

void stop(void) {
    motors(0, 0, 0, 0); // Stop both motors
}

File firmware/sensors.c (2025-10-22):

// * Sergi Marsol Torrent *
// * 2023-10-30 *
// * Microcontroladors i Sistemes Empotrats *
// * Universitat de Barcelona *

#include "sensors.h"
#include "i2c.h"
#include "motors.h"
#include "timer.h"
#include "lcd.h"

#define ADDR 0x10 // I2C address for sensors

volatile uint8_t sensors_out;

void sensors(uint8_t *buffer_out){
    uint8_t i2c_buffer_sensors = 0x1D;
    I2C_send(ADDR, &i2c_buffer_sensors, 1); // Activar
    delay_ms(2);
    I2C_receive(ADDR, buffer_out, 1);
}

void control_movement_lines(uint8_t speed) {
    sensors(&sensors_out); // Read sensor data using the sensors() function

    // Analyze the sensor data and decide the robot's movement
    switch (sensors_out & 0x3F) { // Mask the relevant 6 bits (0x3F -> 00111111)
        case 0x1E: // All 4 sensors detect black (pattern 0x1E → 00011110)
            stop(); // Stop the robot
            write_LCD_one_line("@STOP"); // Display STOP on the LCD
            break;

        case 0x30: // Right sensors detect black (0x30 → 00110000)
        case 0x18: // Right sensors detect black (0x30 → 00011000)
        case 0x10: // Right sensors detect black (0x20 → 00010000)
            turn_right(speed); // Turn right at speed
            write_LCD_one_line("@RIGHT"); // Display RIGHT on the LCD
            break;

        case 0x03: // Left sensors detect black (0x03 → 00000011)
        case 0x06: // Left sensors detect black (0x03 → 00000110)
        case 0x02: // Left sensors detect black (0x02 → 00000010)
            turn_left(speed); // Turn left at speed
            write_LCD_one_line("@LEFT"); // Display LEFT on the LCD
            break;

        case 0x0C: // Center sensors detect black (0x0C → 00001100)
            forward(speed); // Move forward at speed
            write_LCD_one_line("@FORWARD"); // Display FORWARD on the LCD
            break;

        default: // No recognizable signal detected
            stop(); // Stop the robot
            write_LCD_one_line("@STOP"); // Display STOP on the LCD
            break;
    }
}
